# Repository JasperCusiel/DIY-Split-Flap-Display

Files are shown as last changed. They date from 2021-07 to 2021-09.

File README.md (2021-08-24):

# DIY Split-Flap Display

This project is a work in progress and is based on Scott Bez's project found [here](https://github.com/scottbez1/splitflap). The project is aimed around building a low cost split flap module that could be joined to others to form a display. So far the internsion is to get multiple units dasiy chained togeather for a one line display then will work on integrating it for a particular purpose. 

Most current enclosure design | Highlights of design
------------ | -------------
ezgif com-crop-2 | <ul><li>Uses easy to find M4 hardware in standard sizes</li><li>3D printable frame that can also be laser cut</li><li>Uses cheap 28BYJ-48 stepper motors</li><li>Incorperates hall effect sensor for homing the display</li><li>Low cost</li><li>Far sturdier than v1 frame</li><li>Less complex spool mechanisim</li></ul>

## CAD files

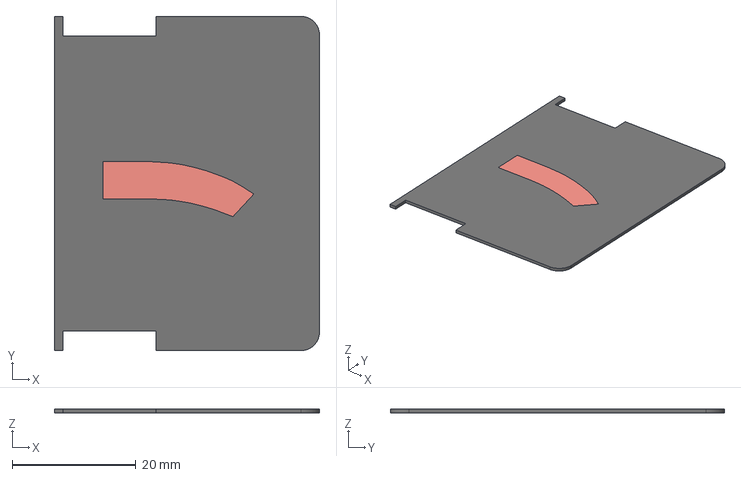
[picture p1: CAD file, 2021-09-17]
Flap #,.step
42.8 x 54.0 x 0.6 mm

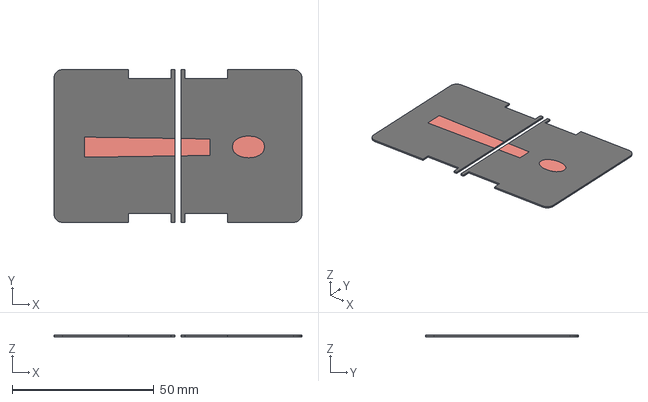
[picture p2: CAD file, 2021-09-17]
Flap 9!#.step
87.6 x 54.0 x 0.6 mm

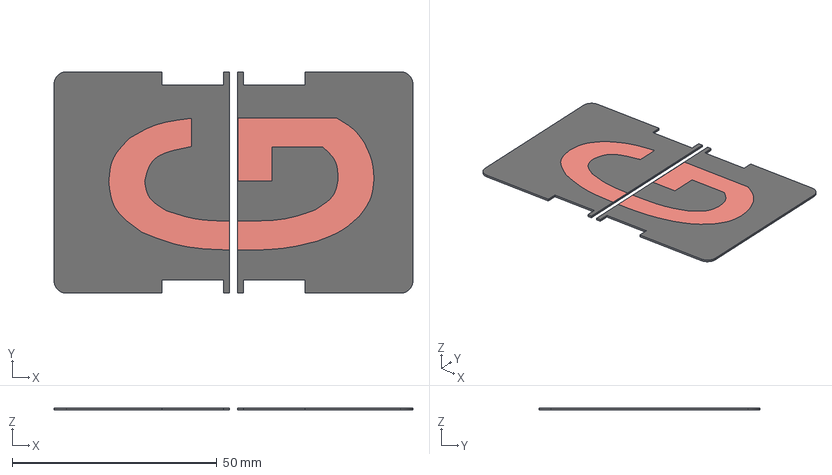
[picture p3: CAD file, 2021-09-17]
Flap FGH.step
87.6 x 54.0 x 0.6 mm

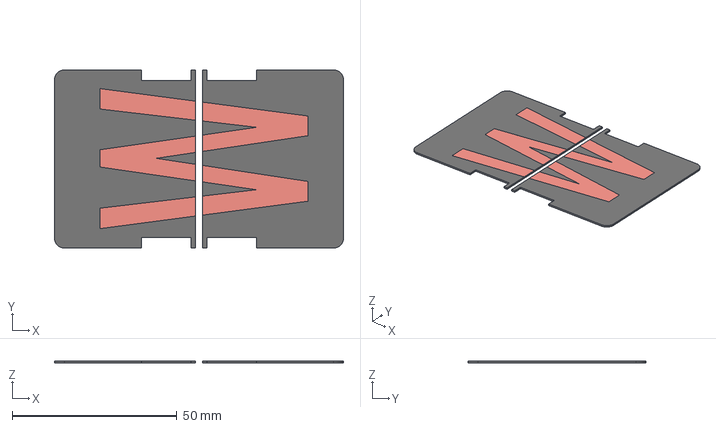
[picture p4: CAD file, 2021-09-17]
Flap VWX.step
87.6 x 54.0 x 0.6 mm

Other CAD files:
Flap HIJ.step
Flap BCD.step
Flap 123.step
Flap LMN.step
Flap Z01.step
Flap RST.step
Flap NOP.step
Flap 567.step
Flap JKL.step
Flap TUV.step
Flap DEF.step
Flap XYZ.step
Flap 345.step
Flap AB.step
Enclosure 2.step
Enclosure V2.0.f3z
Flap 789.step
Flap PQR.step
Flap v1.f3d
M4 bolt nut.step
M4X20 bolt.step
Spool v1.f3z

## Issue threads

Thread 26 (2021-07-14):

Add 3d printing tolerances to spool design

JasperCusiel, 2021-07-14:
parts where hard to fit together as no tolerance was added to the design of the motor shaft interfacing to the outer spool

Closed 2021-07-20.

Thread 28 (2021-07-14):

ULN2003 placment

JasperCusiel, 2021-07-14:

JasperCusiel, 2021-07-14:
A small driver board as found below may be able to fit inside the spool alongside the motor.
https://www.banggood.com/3Pcs-ULN2003-Stepper-Motor-Driver-Board-5-12V-4-Way-Signal-Indicator-p-1188166.html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

Closed 2021-07-21.

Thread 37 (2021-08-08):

redesign enclosure based of Scott bez

JasperCusiel, 2021-08-08:

Closed 2021-08-08.

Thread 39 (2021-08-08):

Add tolerance to mating features

JasperCusiel, 2021-08-08:

JasperCusiel, 2021-08-08:
research tolerances required for laser cutting and adjust pin and slot dimensions

Closed 2021-08-14.

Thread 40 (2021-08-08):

increase bolt hole length

JasperCusiel, 2021-08-08:

JasperCusiel, 2021-08-08:
originally was going to use 10mm bolts but could only buy 15mm m4 bolts which were cheaper

Closed 2021-08-14.

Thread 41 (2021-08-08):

run Hall effect test with new magnets

JasperCusiel, 2021-08-08:

JasperCusiel, 2021-08-08:
new magnets are larger so will probably produce a stronger magnetic field so will need to tune hall sensor values.

JasperCusiel, 2021-08-08:
Woks with new magnets but need to rewrite homing sequence in Arduino code. Also need to create PCB to mount hall sensor on to hold at correct distance from magnet

Closed 2021-08-11.

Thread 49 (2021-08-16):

add tolerance to motor mount and high side

JasperCusiel, 2021-08-16:

Closed 2021-08-16.

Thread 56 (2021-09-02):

Adjust 3d printing tolerance

JasperCusiel, 2021-09-02:

Closed 2021-09-02.

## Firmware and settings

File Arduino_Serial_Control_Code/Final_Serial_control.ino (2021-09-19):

#include <AccelStepper.h>
#include <math.h>

const char *letters[] = {" ", "a", "b", "c", "d", "e", "f", "g", "h", "i", "j", "k", "l", "m", "n", "o", "p", "q", "r", "s", "t", "u", "v", "w", "x", "y", "z", "0","1", "2", "3", "4", "5", "6", "7", "8", "9","!","#", ","};
                           
int positions[] = {0, 52, 104, 156, 208, 260, 312, 364, 416, 475, 520, 572, 624, 676, 728, 780, 832, 884, 946, 988, 1050, 1102, 1144, 1196, 1248, 1300, 1362, 1402, 1456, 1508, 1560, 1612, 1664, 1726, 1768, 1820, 1872, 1924, 1976, 2028};
int num = -51.2;
const char *to_find;
int len = (sizeof (letters) / sizeof (*letters));
int x;
char buffer[128];
String inData;
int stepperPos;
int index;
float numSteps = 0;

#define CMDBUFFER_SIZE 32
#define FULLSTEP 4

int motorPin1 = 9; 
int motorPin2 = 10; 
int motorPin3 = 11; 
int motorPin4 = 12; 

AccelStepper stepper(FULLSTEP, motorPin1, motorPin3, motorPin2, motorPin4);

void setup() {
  Serial.begin(9600);
  //for (int i=0; i<41; i++) {
    //positions[i] = ((num += 52));
    //Serial.println(positions[i]);
 //}
  stepper.setMaxSpeed(1000.0);
  stepper.setAcceleration(10000);
  stepper.setSpeed(1000);
  homeDisplay();
   
}


void loop() {
  moveStepper();
  serialIn();
  }

void serialIn() {
  static char cmdBuffer[CMDBUFFER_SIZE] = "";
  char c;
  if(Serial.available() > 0) {
    c = processCharInput(cmdBuffer, Serial.read());
    if (c == '\n') {
      getLetterIndex(cmdBuffer);
      Serial.println("Letter: "+ String(cmdBuffer));
      cmdBuffer[0] = 0;
    }      
  }
}

void homeDisplay() {
  int sensorPin = A6;
  int sensorValue = 500;
  pinMode(sensorPin, INPUT_PULLUP);
  stepper.setSpeed(700);
  while (sensorValue >= 200) {
    sensorValue = analogRead(sensorPin);
    stepper.runSpeed();
  }
  stepper.setCurrentPosition(52);
  Serial.println("Module Homed");
}


void getPositionByIndex(int index) {
  Serial.println("Position: " + String(positions[index]));
  if (int(positions[index]) == 0 and stepper.currentPosition() == 2048) {
    stepper.moveTo(2100);
    stepper.setCurrentPosition(0);
  }
  
  else if (int(positions[index]) < stepper.currentPosition()) {
    stepper.moveTo(2048);
    moveStepper();
    stepper.setCurrentPosition(0);
    stepper.moveTo(int(positions[index]));
  }
  else {
    stepper.moveTo(positions[index]);
  }
  
}

void moveStepper() {
  while (stepper.distanceToGo() > 0) {
    stepper.run(); 
  }
  stepper.disableOutputs();
}

void getLetterIndex(const char *letter) {
  for (x = 0; x < len; x++) {
    if (strcmp (letter, letters[x]) == 0) {
      getPositionByIndex(x);
    } 
  }
}

char processCharInput(char* cmdBuffer, const char c) {
  if (c >= 32 && c <= 126) {
    if (strlen(cmdBuffer) < CMDBUFFER_SIZE) { 
      strncat(cmdBuffer, &c, 1);   //Add it to the buffer
    }
    else {   
      return '\n';
    }
  }
  
  else if ((c == 8 || c == 127) && cmdBuffer[0] != 0) {
    cmdBuffer[strlen(cmdBuffer)-1] = 0;
  }
  return c;
}

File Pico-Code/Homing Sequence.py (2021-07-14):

import time
from machine import Pin, ADC

FULL_ROTATION = int(4075.7728395061727 / 8)

LOW = 0
HIGH = 1
HALF_STEP = [
    [LOW, LOW, LOW, HIGH],
    [LOW, LOW, HIGH, HIGH],
    [LOW, LOW, HIGH, LOW],
    [LOW, HIGH, HIGH, LOW],
    [LOW, HIGH, LOW, LOW],
    [HIGH, HIGH, LOW, LOW],
    [HIGH, LOW, LOW, LOW],
    [HIGH, LOW, LOW, HIGH]]
DELAY = 0.001

class Command:
    """Tell a stepper to move X many steps in direction"""
    def __init__(self, stepper, steps, direction):
        self.stepper = stepper
        self.steps = steps
        self.direction = direction

class Stepper:
    
    def __init__(self, mode, pin1, pin2, pin3, pin4):
        self.mode = mode
        self.pin1 = Pin(pin1, Pin.OUT)
        self.pin2 = Pin(pin2, Pin.OUT)
        self.pin3 = Pin(pin3, Pin.OUT)
        self.pin4 = Pin(pin4, Pin.OUT)
        """set all pins to low, stepper wont consume any power"""
        self.reset()

    def step(self, count, direction):
        """Rotate count steps. direction = -1 means backwards"""
        for x in range(count):
            for bit in self.mode[::direction]:
                self.pin1.value(bit[0])
                self.pin2.value(bit[1])
                self.pin3.value(bit[2])
                self.pin4.value(bit[3])
                time.sleep(DELAY)
        self.reset()

    def reset(self):
        # Reset to 0, no holding, these are geared, you can't move them
        self.pin1.value(0)
        self.pin2.value(0)
        self.pin3.value(0)
        self.pin4.value(0)
        
class Driver:
    """Drive a set of motors, each with their own commands"""

    @staticmethod
    def run(commands):
        """Takes a list of commands and interleaves their step calls"""

        # Work out total steps to take
        max_steps = sum([c.steps for c in commands])

        count = 0
        while count != max_steps:
            for command in commands:
                # we want to interleave the commands
                if command.steps > 0:
                    command.stepper.step(1, command.direction)
                    command.steps -= 1
                    count += 1
        
if __name__ == '__main__':
    analog_value = ADC(26)
    s1 = Stepper(HALF_STEP, 9, 8, 7, 6)
    
    
    runner = Driver()
    def home(stepper):
        counter = 0
        home_found = False
        print("Searching for home position")
        while home_found != True:
            if counter > 550 and home_found != True:
                print("Home not found, Retrying")
                time.sleep(5)
                home(stepper)
                counter = 0
            else:
                reading = analog_value.read_u16()     
                # print("ADC: ",reading)
                if reading < 18000:
                    stepper.reset()
                    home_found = True
                else:
                    runner.run([Command(stepper, 1, 1)])
                    counter += 1
        print("Home position found!")
    home(s1)

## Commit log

2021-07-13 Flap v1
    First flap iteration based upon dimensions found here: https://github.com/gregerw/Split-flap-display/blob/master/CAD/flaps/flapDrawing.PDF
    [Flap v1.f3d]
2021-07-13 Spool Assembly
    Spool assembly including motor mount, spool, spool mount, 28BYJ-48 stepper, possible mounting hardware, hall effect sensor, and flap. Note: is a Fusion 360 assembly not individule parts
    [Spool v1.f3z]
2021-07-13 Stepper motor moves continously
    First test into driving the stepper motor through the ULN2003 driver. Code makes stepper rotate continuosly with a set velocity
2021-07-14 Hall Effect Test
    Moves stepper motor until the hall effect sensors reading is less than a specified threshold.
2021-07-14 Rename Continuous stepper rotation to Pico-Code/Continuous stepper rotation
2021-07-14 ULN2003 driver
    Program based upon the driver code found here: https://github.com/IDWizard/uln2003/blob/master/uln2003.py that was adapted to run on the Pi Pico suing its machine library.
2021-07-14 Rename Pico-Code/Continuous stepper rotation to Pico-Code/Testing Code/Continuous stepper rotation
2021-07-14 Rename Pico-Code/Testing-Code/Hall-Effect-Test to Pico-Code/Testing Code/Hall-Effect-Test
2021-07-14 Homing Sequnece
    Added Function 'home' to the driver code. The spool rotates slightly past a full rotation to find the home position. If it is not found an error message is displayed and the code will re-run to try to find the home position again. If found a success message is displayed.
2021-07-14 Rename Homing Sequence to Homing Sequence.py
2021-07-14 Rename Continuous stepper rotation to Continuous stepper rotation.py
2021-07-14 Create Display-Hall-Value.py
    Prints hall effect reading. Used to determine the value produced by bringing a magnet over the sensor which is used in the homing sequence as value at which the magnet is directly over the hall effec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
2021-08-22 Enclosure v2
    Enclosure design based on Scott bez's project here https://github.com/scottbez1/splitflap
    [Enclosure v2.f3z]
2021-08-25 Update Constant_Speed.ino
    175 speed was slightly to fast for only running on 5v as it became jammed at points
2021-08-25 Delete Enclosure v2.f3z
    New version created
    [Enclosure v2.f3z]
2021-08-25 Add files via upload
    Version 2.0 frame - fixes tolerance issues
    [Enclosure V2.0.f3z]
2021-09-17 Final Enclosure Design with 3D printing tolerances
    Includes all relevant parts
    [Enclosure 2.step, M4 bolt nut.step, M4X20 bolt.step]
2021-09-17 Flaps with letters
    Designed for multi coloured 3d printing
    [Flap #,.step, Flap 123.step, Flap 345.step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]
